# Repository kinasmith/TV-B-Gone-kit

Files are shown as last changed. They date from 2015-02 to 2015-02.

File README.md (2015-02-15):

# TV-B-Gone
### The SMD version

This is a fork of [Adafruit's tv b gone kit](https://github.com/adafruit/TV-B-Gone-kit). I added a lithium charging and protection circuit, and converted the board to be surface mount. It is single-sided and can be made easily on a circuit mill. 

It is tested and works.

## Notes:

avrdude -c avrispmkII -p t85 -B 250 -u -U lfuse:w:0xfd:m -U hfuse:w:0xdf:m

avrdude -c avrispmkII -p t85 -b 19200 -U flash:w:tvbgone.hex:i

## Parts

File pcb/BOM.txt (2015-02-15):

Partlist exported from /Users/kina/Documents/eagle/TV-B-Gone-kit/pcb/tvbgone3.sch at 2/15/15 9:57 AM

Part Value                     Device                    Package            Description                                                                             
C1   0.1uF                     0.1UF-25V-5%(0603)        0603-CAP           CAP-08604                                                                               
C2   100uF                     CAP_POLC                  PANASONIC_C        Capacitor Polarized                                                                     
C4   4.7uF                     0.22UF50V-20%,+80%(0603)  0603-CAP           CAP-09885                                                                               
C5   0.1uF                     0.22UF50V-20%,+80%(0603)  0603-CAP           CAP-09885                                                                               
D1   BLUE                      LED-BLUE0603              LED-0603           Blue LEDs for production use                                                            
ICSP                           M03X2SMT                  2X3_SMT_POSTS      2x3 .1" header.                                                                         
J1                             JST_2MM_MALE              JST-2-SMD          Mates to single-cell LiPo batteries.                                                    
JP1  LED4                      M02PTH3                   1X02_LONGPADS      Standard 2-pin 0.1" header. Use with                                                    
JP2  LED3                      M02PTH3                   1X02_LONGPADS      Standard 2-pin 0.1" header. Use with                                                    
JP3  LED2                      M02PTH3                   1X02_LONGPADS      Standard 2-pin 0.1" header. Use with                                                    
JP4  LED1                      M02PTH3                   1X02_LONGPADS      Standard 2-pin 0.1" header. Use with                                                    
JP5  BTTN                      M02PTH3                   1X02_LONGPADS      Standard 2-pin 0.1" header. Use with                                                    
JP6                            M03SMD_RA_MALE            1X03_SMD_RA_MALE   Header 3                                                                                
LED5 RED                       LED0603                   LED-0603           LEDs                                                                                    
Q1   MMBT5088                  TRANSISTOR_NPNMMBT5088    SOT23              Generic NPN BJT                                                                         
Q2   MMBT5088                  TRANSISTOR_NPNMMBT5088    SOT23              Generic NPN BJT                                                                         
Q3   MMBT5088                  TRANSISTOR_NPNMMBT5088    SOT23              Generic NPN BJT                                                                         
Q4   MMBT5088                  TRANSISTOR_NPNMMBT5088    SOT23              Generic NPN BJT                                                                         
Q5   MMBT4403                  TRANSISTOR_PNPMMBT4403    SOT23              Generic PNP BJT                                                                         
Q6   MOSFET-NCHANNELBSS123LT1G MOSFET-NCHANNELBSS123LT1G SOT23              Common NMOSFET Parts                                                                    
Q7   MOSFET-NCHANNELBSS123LT1G MOSFET-NCHANNELBSS123LT1G SOT23              Common NMOSFET Parts                                                                    
R1   1K                        2MOHMS-1/10W-1%(0603)     0603-RES           RES-10054                                                                               
R2   10k(opt)                  2MOHMS-1/10W-1%(0603)     0603-RES           RES-10054                                                                               
R3   1k                        3.3MOHM-1/10W-1%(0603)    0603-RES           RES-11057                                                                               
R4   2K                        3.3MOHM-1/10W-1%(0603)    0603-RES           RES-11057                                                                               
R5   1k                        2MOHMS-1/10W-1%(0603)     0603-RES           RES-10054                                                                               
R6   1K                        3.3MOHM-1/10W-1%(0603)    0603-RES           RES-11057                                                                               
U$1  CTSCE8M_00G52             CTSCE8M_00G52             CSTCE                                                                                                      
U$2  USB-MINIB-5PIN            USB-MINIB-5PIN            USB-MINIB          Mini-USB "B" connector with 5th pin broken out.                                         
U1   ATTINY85V-10SU            ATTINY85V-10SU            SOIC127P798X216-8N 8-bit Microcontroller with In-System Programmable Flash                                 
U2                             S-8241                    SOT23-5L           Seiko S-8241                                                                            
U3   MCP73831                  MCP73831                  SOT23-5            Miniature single cell, fully integrated Li-Ion, Li-polymer charge management controller

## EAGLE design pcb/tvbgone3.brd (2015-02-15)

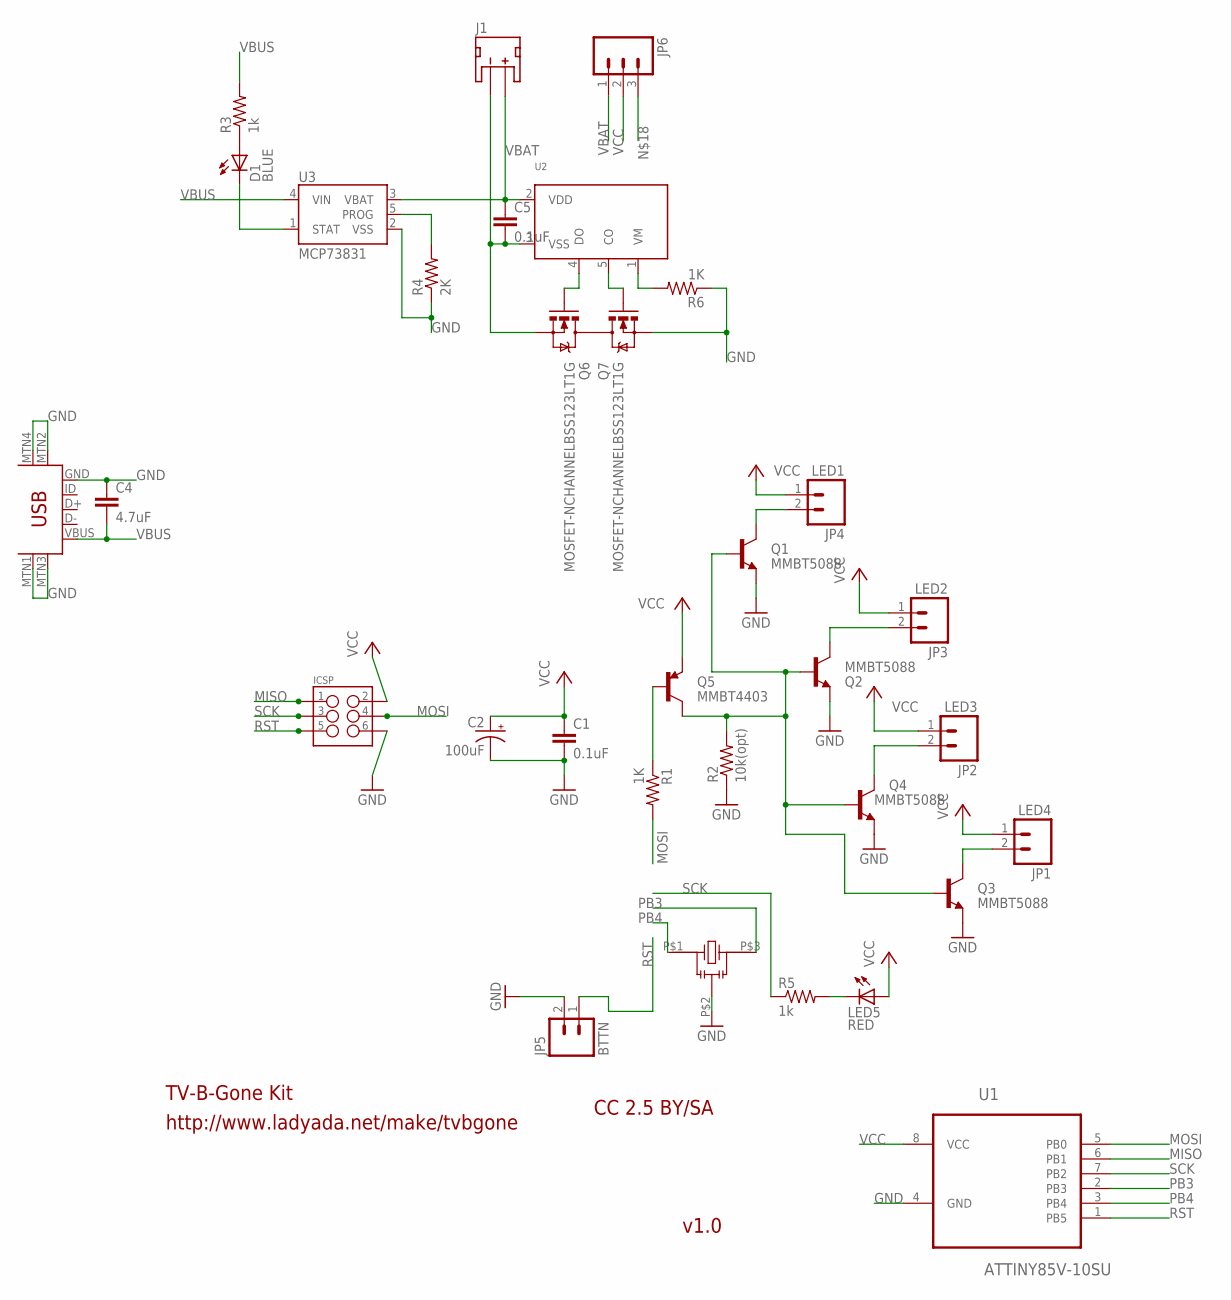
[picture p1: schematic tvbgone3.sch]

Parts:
C1, C5: 0.1uF; 0603-CAP
C2: 100uF; PANASONIC_C
C4: 4.7uF; 0603-CAP
D1: BLUE; LED-0603
ICSP: M03X2SMT; 2X3_SMT_POSTS
J1: JST_2MM_MALE; JST-2-SMD
JP1: LED4; 1X02_LONGPADS
JP2: LED3; 1X02_LONGPADS
JP3: LED2; 1X02_LONGPADS
JP4: LED1; 1X02_LONGPADS
JP5: BTTN; 1X02_LONGPADS
JP6: M03SMD_RA_MALE; 1X03_SMD_RA_MALE
LED5: RED; LED-0603
Q1, Q2, Q3, Q4: MMBT5088; SOT23
Q5: MMBT4403; SOT23
Q6, Q7: MOSFET-NCHANNELBSS123LT1G; SOT23
R1, R6: 1K; 0603-RES
R2: 10k(opt); 0603-RES
R3, R5: 1k; 0603-RES
R4: 2K; 0603-RES
U1: ATTINY85V-10SU; SOIC127P798X216-8N
U2: S-8241; SOT23-5L
U3: MCP73831; SOT23-5
U$1: CTSCE8M_00G52; CSTCE
U$2: USB-MINIB-5PIN; USB-MINIB

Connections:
GND: C1.2, C2.-, C4.1, ICSP.6, JP5.2, Q1.2 (E), Q2.2 (E), Q3.2 (E), Q4.2 (E), Q7.2 (S), R2.1, R4.1, R6.1, U1.4 (GND), U3.2 (VSS), U$1.P$2, U$2.GND, U$2.MTN1 (MTN2), U$2.MTN2 (MTN3), U$2.MTN3 (MTN1), U$2.MTN4
MISO: ICSP.1, U1.6 (PB1)
MOSI: ICSP.4, R1.2, U1.5 (PB0)
unnamed: JP4.2, Q1.3 (C)
unnamed: JP3.2, Q2.3 (C)
unnamed: LED5.C, R5.2
unnamed: JP1.2, Q3.3 (C)
unnamed: C5.2, J1.1 (-), Q6.2 (S), U2.3 (VSS)
unnamed: Q5.1 (B), R1.1
unnamed: JP2.2, Q4.3 (C)
unnamed: D1.C, U3.1 (STAT)
unnamed: D1.A, R3.1
unnamed: Q1.1 (B), Q2.1 (B), Q3.1 (B), Q4.1 (B), Q5.3 (C), R2.2
unnamed: R4.2, U3.5 (PROG)
unnamed: Q6.3 (D), Q7.3 (D)
unnamed: Q6.1 (G), U2.4 (DO)
unnamed: Q7.1 (G), U2.5 (CO)
unnamed: R6.2, U2.1 (VM)
PB3: U1.2 (PB3), U$1.P$3
PB4: U1.3 (PB4), U$1.P$1
RST: ICSP.5, JP5.1, U1.1 (PB5)
SCK: ICSP.3, R5.1, U1.7 (PB2)
VBAT: C5.1, J1.2 (+), JP6.1, U2.2 (VDD), U3.3 (VBAT)
VBUS: C4.2, R3.2, U3.4 (VIN), U$2.VBUS
VCC: C1.1, C2.+, ICSP.2, JP1.1, JP2.1, JP3.1, JP4.1, JP6.2, LED5.A, Q5.2 (E), U1.8 (VCC)

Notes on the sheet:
http://www.ladyada.net/make/tvbgone
TV-B-Gone Kit
v1.0
CC 2.5 BY/SA

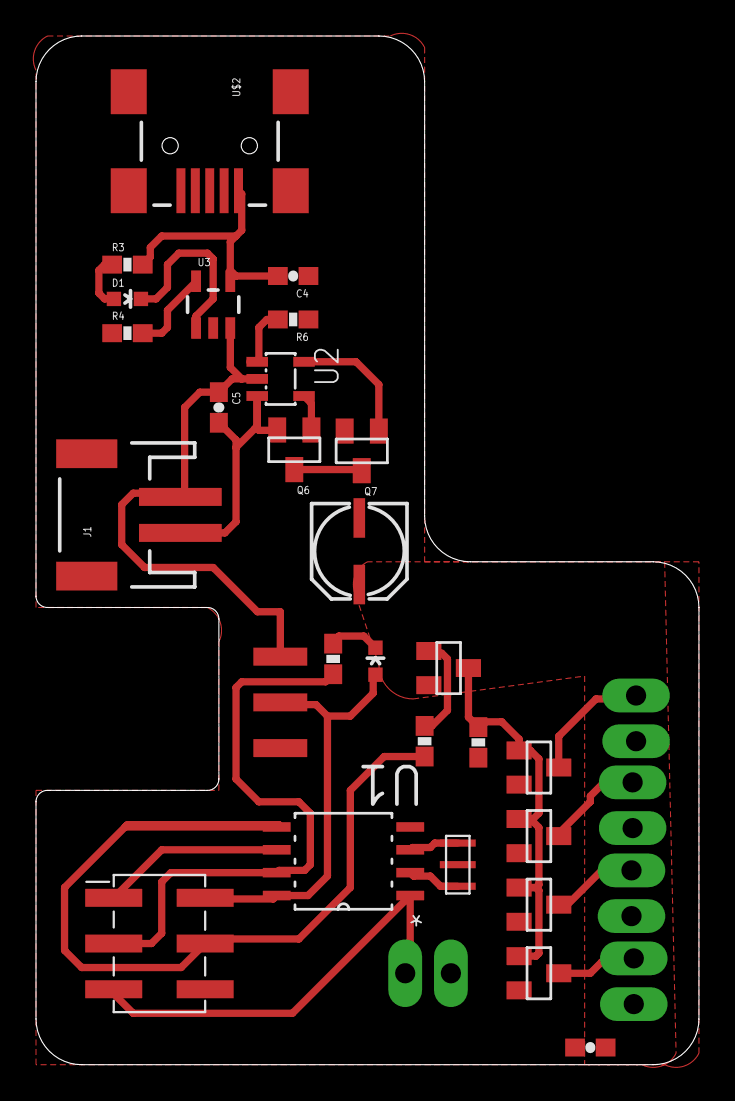
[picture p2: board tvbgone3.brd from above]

Board: 2 copper layers, 36.8 x 57.1 mm, 32 parts (0 on the bottom side), 25 nets.

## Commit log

2015-02-15 version 1 of the new board design done
2015-02-15 finalized version 1 of smd board and documented the fuses. Tested. It Works\!
    [tvbgone3.brd, tvbgone3.sch]

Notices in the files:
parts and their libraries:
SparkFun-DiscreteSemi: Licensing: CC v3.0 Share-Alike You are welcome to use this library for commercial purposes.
